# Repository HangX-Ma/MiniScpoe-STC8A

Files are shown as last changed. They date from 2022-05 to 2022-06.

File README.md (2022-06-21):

# :rocket: MiniScope on STC8A8K64D4

  

I want to use this **MiniScope** project to learn embedded system. I imitate [Open-ELL/MiniDSO-Pro](https://gitee.com/open-ell/mini-dso-pro) to make a **MiniScope** on my own but the hardware and software seems not suitable for me on account of self-changes. I have written a convenient system library for _STC8x_ easy usage. Currently I only finish the _STC8Ax_ and _STC8Hx_(mainly based on _STC8A8K64D_). **NEW DESIGN AVAILABLE PUBLISHED at 20220621.**

## Test Recorder
- [x] ADC Inquiry Method
- [x] ADC `VBAT` Module
- [x] UARTx Module
- [x] External Interrupt 0 and 1
- [x] TM0 and TM1 for keys scanning and VBAT information update
- [x] EEPROM Module
- [x] SSD1306 OLED
- [x] Setting options selection
- [x] Chart options selection
- [x] Wave scroll options selection
- [x] Run/Stop function

**NOTE: EC11 external Interrupt seems wrong. I think this may cause by hardware design or the EC11 device itself.**

## New Design

### PCB 3D Perspective
<center class="half">
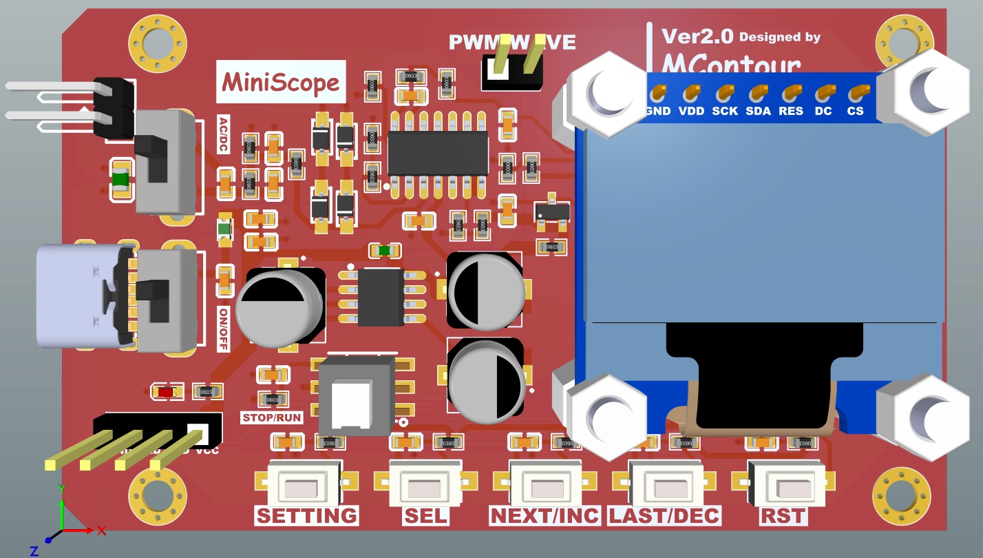
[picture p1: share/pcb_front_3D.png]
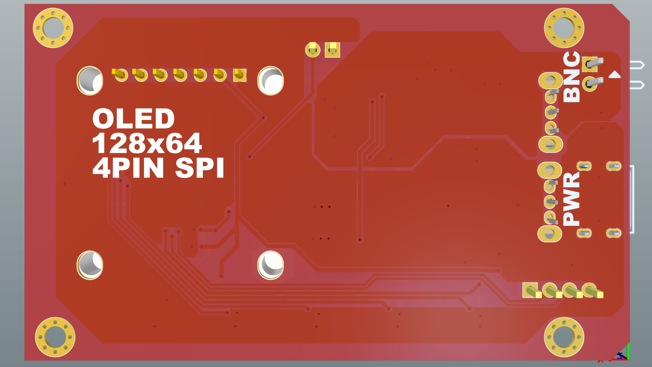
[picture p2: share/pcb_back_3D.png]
     
</center>

### PCB 2D Perspective
<center class="half">
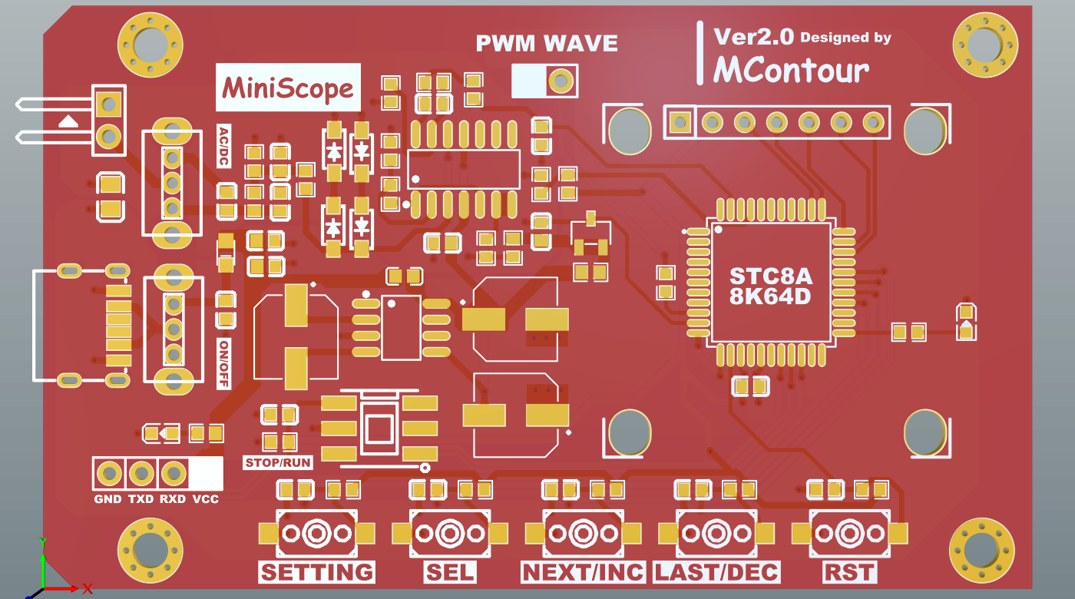
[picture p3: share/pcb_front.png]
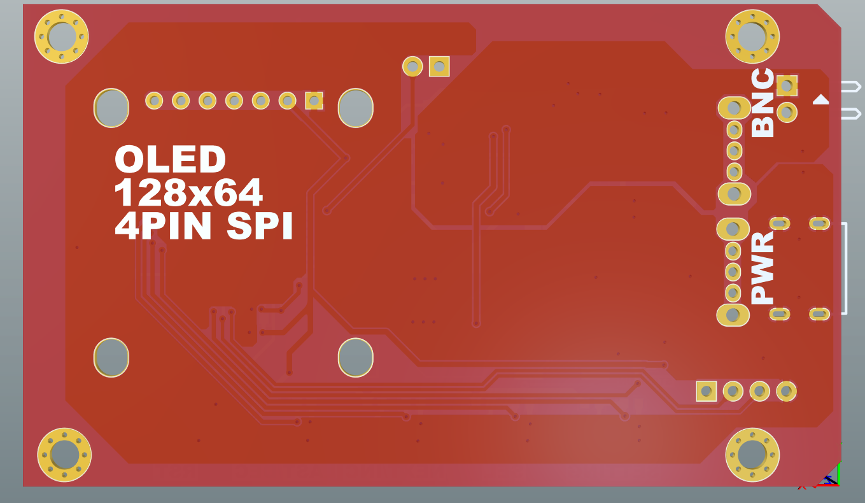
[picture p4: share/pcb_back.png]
     
</center>

### Timer Source Usage
- `TM0`: VBAT info updating rate
- `TM1`: Keys press types recognition, short or long
- `TM3`: UART1 Rx out of time

### FUNCTION INTRODUCTION

#### OPERATION INTRO:
##### Main Interface - Options Selection Mode: 
- `SW Button`:              Switch Stop/Run
- `Short Press SETTING`:    Switch to [Waveform Horizontal Scroll Mode]
- `SEL`:                    Select or deselect this option.
- `NEXT/INC`:               Jump to next option or increase value.
- `LAST/DEC`:               Jump to last option or decrease value.

##### Main Interface - Waveform Horizontal Scroll Mode:
- `SW Button`:              Switch Stop/Run
- `Short Press SETTING`:    Switch to [Options Selection Mode]
- `[SEL] SET(Horizontal waveform scroll, Valid in suspended sampling state)`:
  - `NEXT/INC`:           Jump to next option or increase value.
  - `LAST/DEC`:           Jump to last option or decrease value.
- `[SEL] RESET(Vertical waveform scroll, Valid in suspended sampling state):`
    `NEXT/INC`:           Jump to next option or increase value.
    `LAST/DEC`:           Jump to last option or decrease value.

##### Setting Interface: (SETTING)
- `Long Press SETTING`: Return to main interface or enter setting interface from main interface.
- `SEL`:                    Select or de-select this option.
- `NEXT/INC`:               Jump to next option or increase value.
- `LAST/DEC`:               Jump to last option or decrease value.

#### MAIN INTERFACE INTRO:
- `Vertical Time Range`:     "500ms", "200ms", "100ms", "50ms", "20ms", "10ms","5ms", "2ms", "1ms", "500us", "200us", "100us"(100us only used in AUTO Mode)
- `Horizontal Voltage Range`: Set voltage upper range, whose maximum value is 30V. If the voltage upper range is set to '0', system run into AUTO mode.
- `Trigger Value`:            Set trigger voltage value. The trigger position is set to the screen center.
- `Trigger Direction`:        Use up or down arrow indicator, separately representing rising edge trigger and falling edge trigger.
- `Trigger Mode`:
  - `AUTO`:   Sample continuously, whose indicator led is always turned on. SW Button is used to select RUN or STOP;
                If trigger process is successful, trigger position is set to the screen center, otherwise the waveform scrolling irregularly. FAIL will be shown.
  - `NORMAL`: Wait for prerequisite sampling. Indicator led is turned on, indicating the prerequisite sampling finished. Signal can be entered.
                After successfully triggering, display the waveform, and continue to wait for the next trigger;
                If a new trigger is successful, the new waveform will be displayed automatically. If no new trigger is successful, the screen waveform will remain and wait for the next trigger;
                (Be careful to set the correct trigger value, otherwise has been waiting for the trigger state, the screen will not display the waveform)
  - `SINGLE`: Wait for prerequisite sampling. Indicator led is turned on, indicating the prerequisite sampling finished. Signal can be entered.
                After triggering successfully, display the waveform and stop sampling, the user needs to click on the encoder to start the next sampling.
                (Be careful to set the correct trigger value, otherwise has been waiting for the trigger state, the screen will not display the waveform)

#### OPTIONS SETTING SAVING:
Long press SETTING key to leave the setting interface. If options have been changed, the program will save the setting to EEPROM.

#### LVD EVENT:
If LVD event happens, system will not allow user to operate EEPROM to save data.

#### MAIN INTERFACE STATUS: 
- `RUN`:        Sampling in progress 
- `STOP`:       Stop Sampling 
- `FAIL`:       In AUTO mode, trigger value exceeds waveform range causing trigger failure 
- `SUCC`:       In automatic mode, the trigger value displays the trigger success in the waveform range.
- `AUTO`:       Auto range.

#### SETTING INTERFACE STATUS: 
- `PMODE (drawing mode)`: 
  - Vector: waveform display using vector 
  - Dots:   waveform display using dots
- `LSB (sampling factor)`: 100 times the partial voltage factor, (8.2K+2K)/2K*100 = 510. Adjust this value subtly in accordance with actual register values.
- `BRT`:    OLED brightness

> Reference: [Open-ELL/MiniDSO-Pro](https://gitee.com/open-ell/mini-dso-pro)
> Reference: [CreativeLau/Mini-DSO](https://github.com/CreativeLau/Mini-DSO)

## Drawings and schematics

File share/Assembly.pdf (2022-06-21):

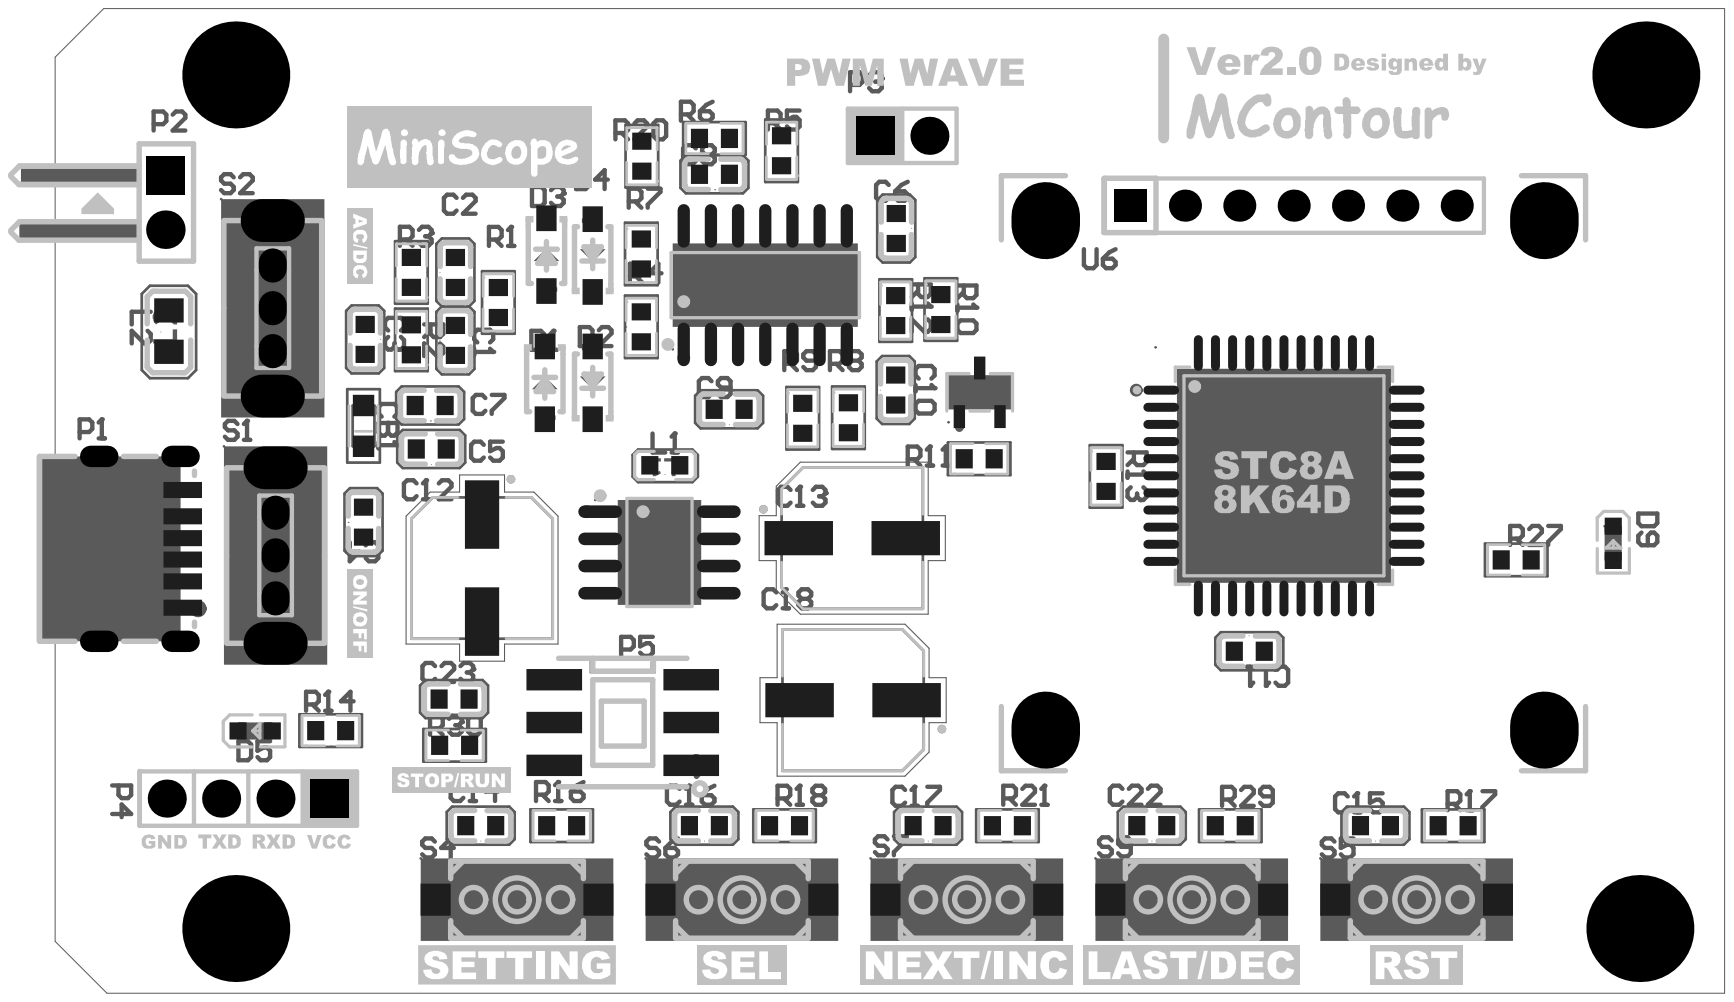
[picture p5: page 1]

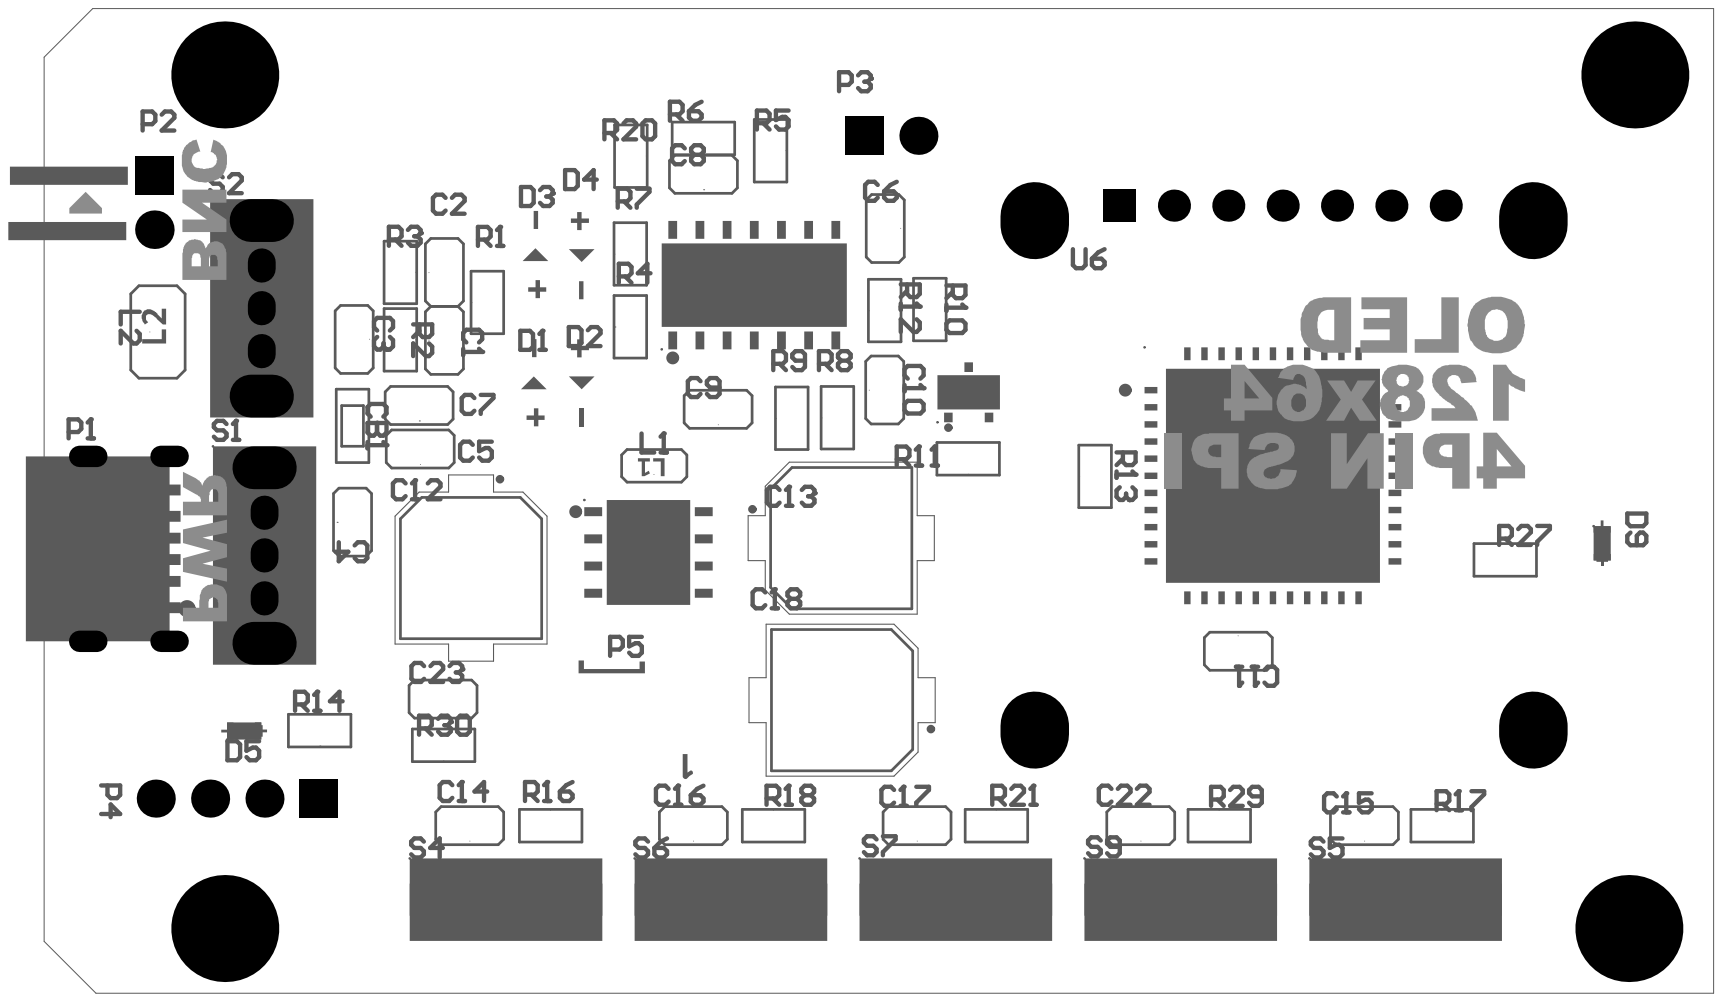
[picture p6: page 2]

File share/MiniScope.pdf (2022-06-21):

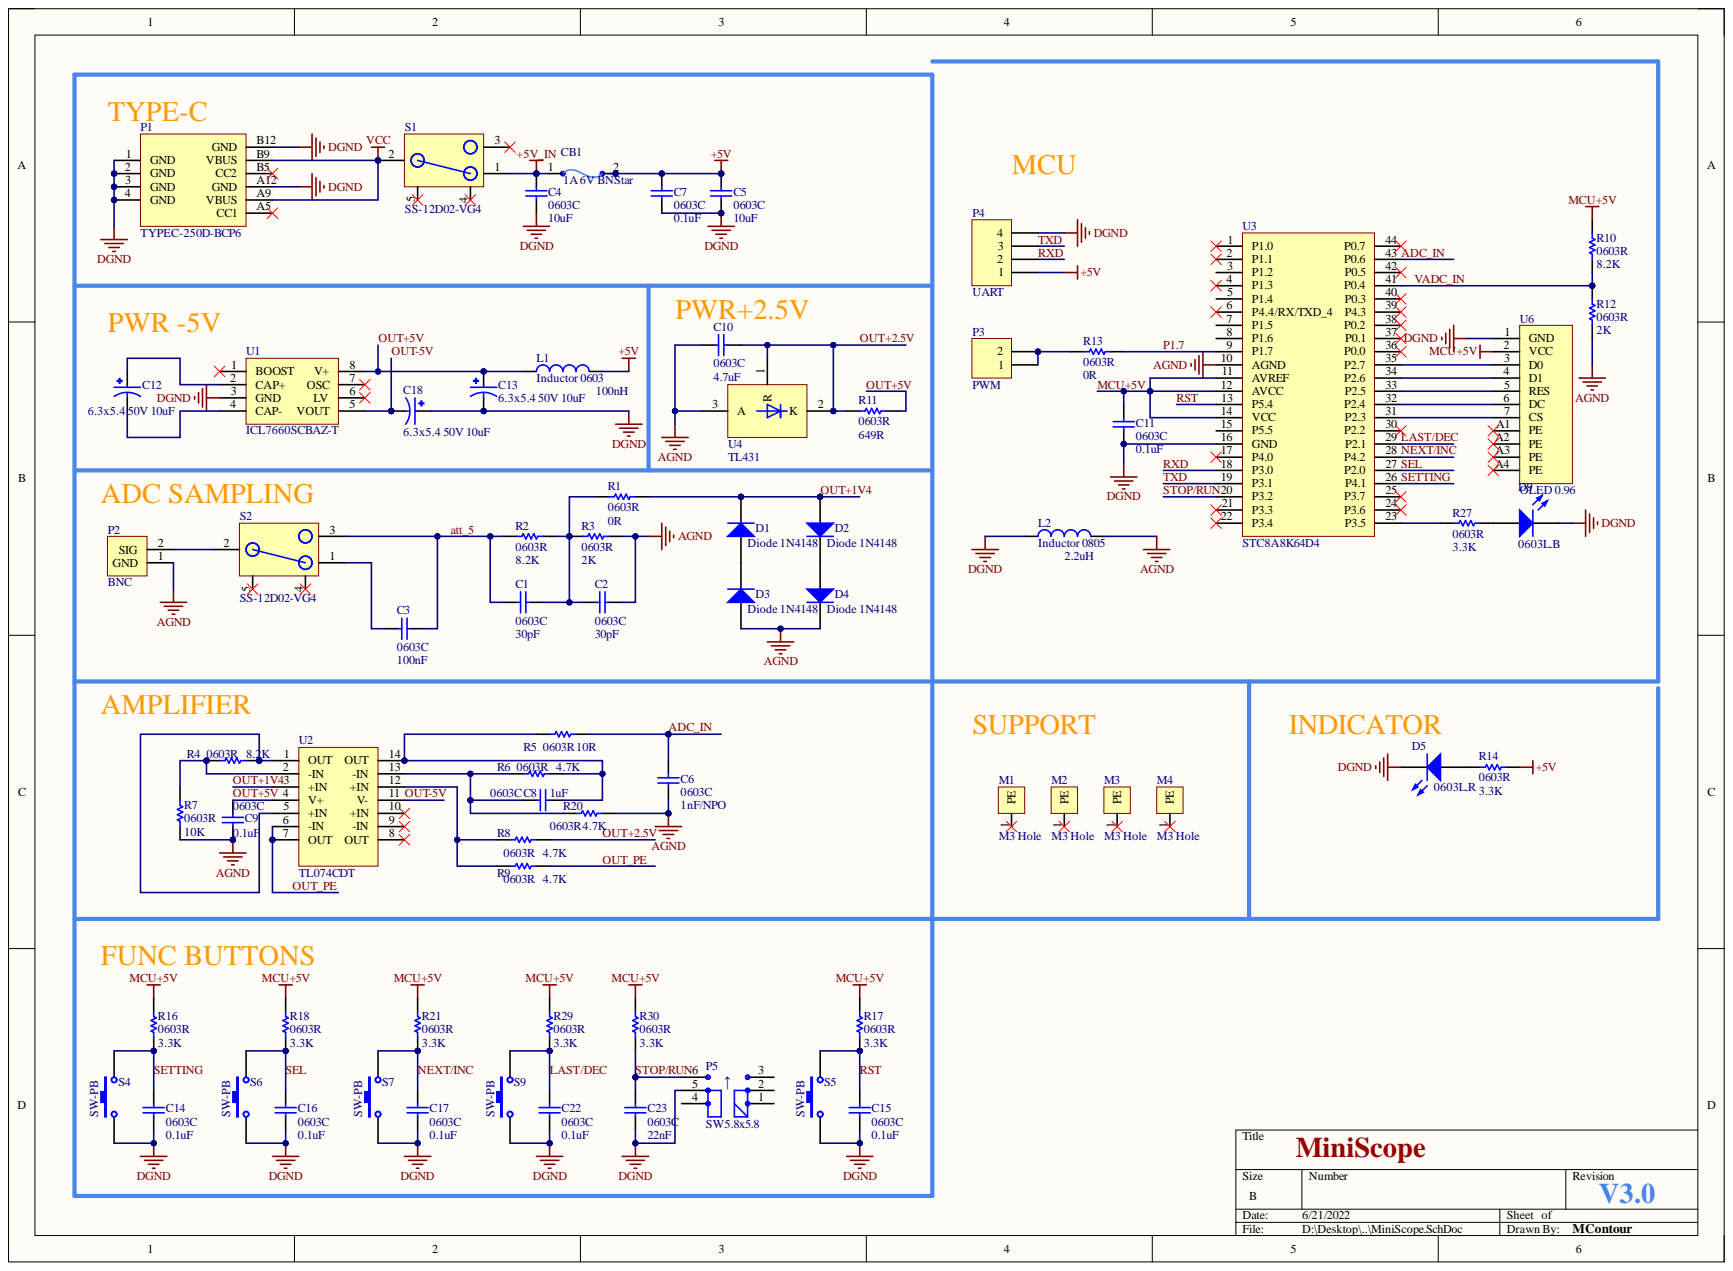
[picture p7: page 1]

AVREF 11 | | D1 4
AVCC 12 | | RES 5

C11 | VCC 14 | | CS 7

P5.5 15 | LAST/DEC | PE A1

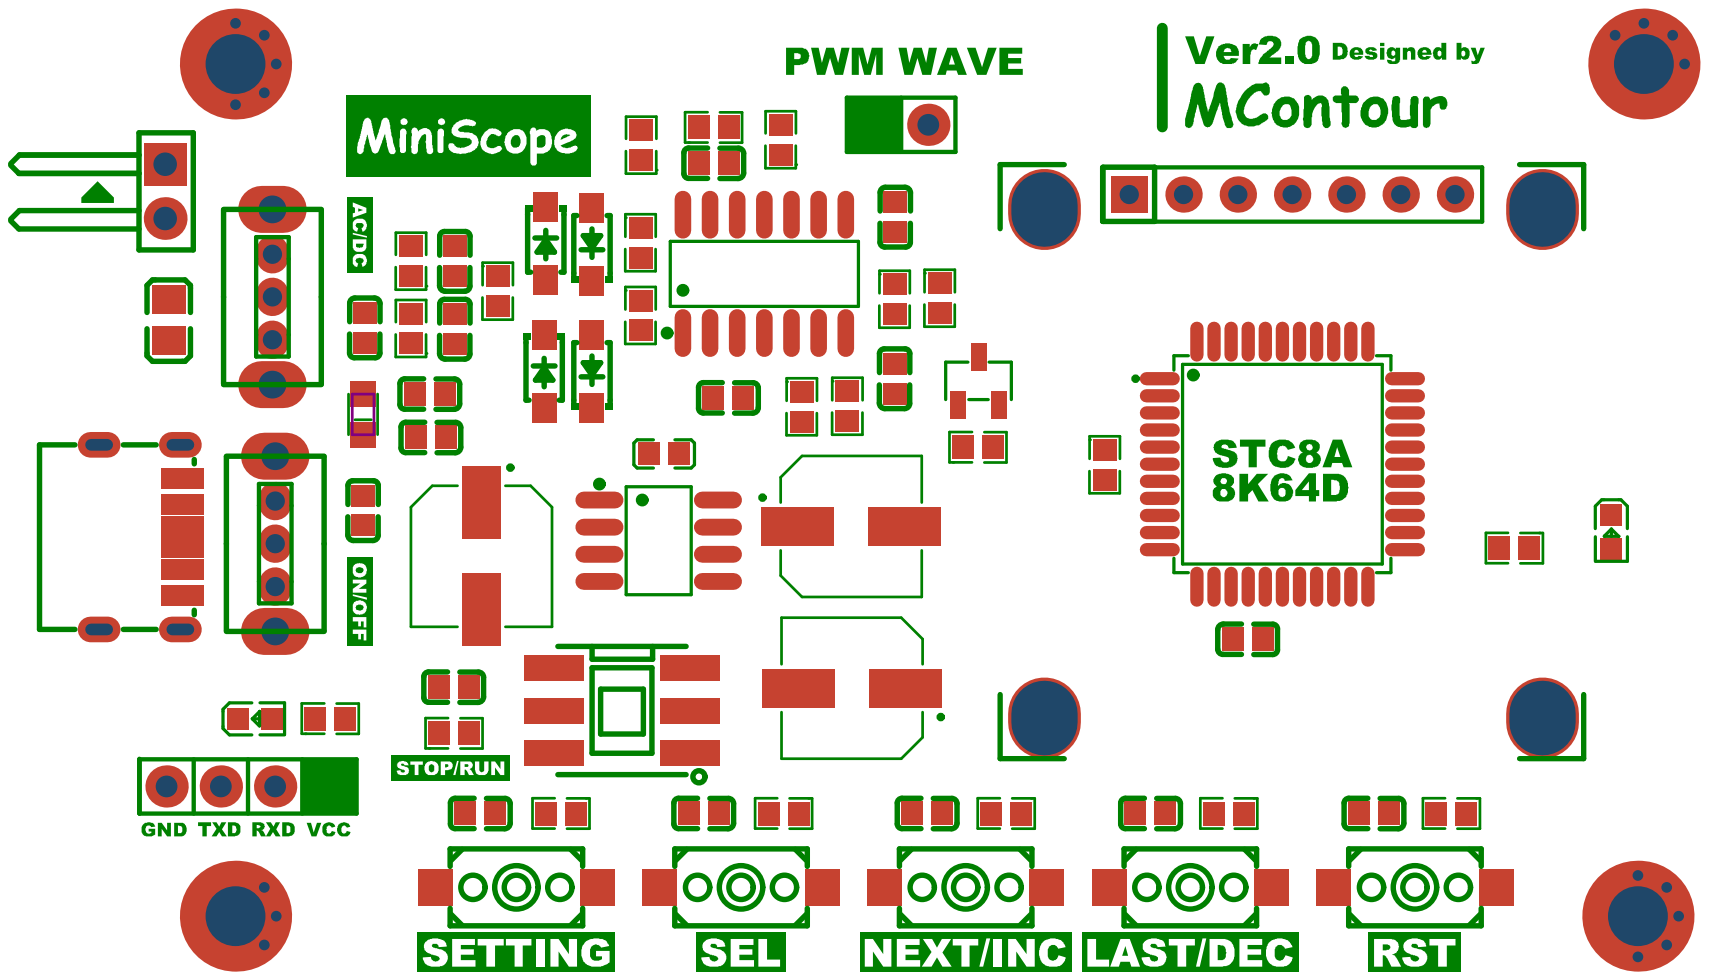
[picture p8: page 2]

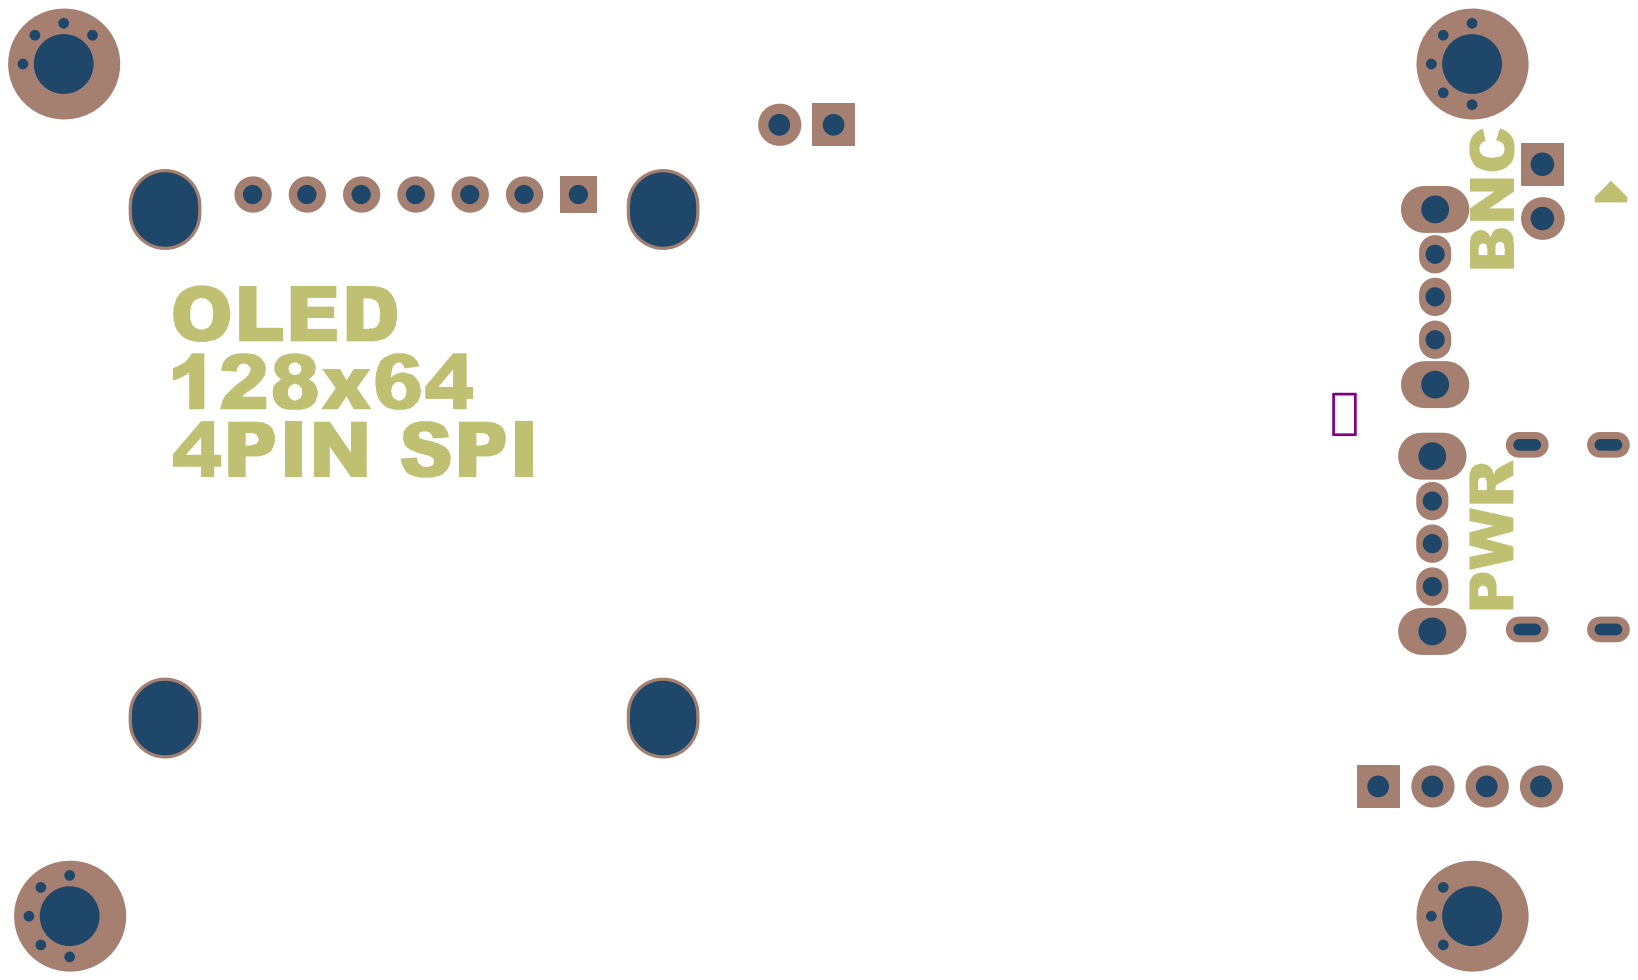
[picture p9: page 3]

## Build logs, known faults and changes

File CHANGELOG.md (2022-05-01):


## [v1.2](https://github.com/Master-sx/MiniScpoe-STC8A.git/compare/v1.1...v1.2) (2022-05-01)

### Feat

* :white_check_mark: Easy set or reset definitions

### Perf

* :white_check_mark: Core configuration for STC8A v5.0

## [v1.1](https://github.com/Master-sx/MiniScpoe-STC8A.git/compare/v1.0.4...v1.1) (2022-05-01)

### Perf

* Core configuration of STC8A v4.0
* STC8A core configuration v3.0
* Core configuration for STC8A v2.0
* Core configuration for STC8A v1.0

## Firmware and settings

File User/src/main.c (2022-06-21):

/**
 * @file main.c
 * @author MContour (m-contour@qq.com)
 * @brief main program
 * @version 0.1
 * @date 2022-05-06
 * 
 * @copyright Apache 2.0 LICENSE
 * 
 *****************************************************************************
 * Copyright (c) 2022 MContour m-contour@qq.com
 *
 * Licensed under the Apache License, Version 2.0 (the "License");
 * you may not use this file except in compliance with the License.
 * You may obtain a copy of the License at
 * 
 *     http://www.apache.org/licenses/LICENSE-2.0
 * 
 * Unless required by applicable law or agreed to in writing, software
 * distributed under the License is distributed on an "AS IS" BASIS,
 * WITHOUT WARRANTIES OR CONDITIONS OF ANY KIND, either express or implied.
 * See the License for the specific language governing permissions and
 * limitations under the License.
 *****************************************************************************
 */

/* TM0: VBAT info updating rate */
/* TM1: Keys press types recognition, short or long */
/* TM3: UART1 Rx out of time */

/*
    -----------------------------------------  [INTRODUCTION]  -----------------------------------------
    OPERATION INTRO:
        Main Interface - Options Selection Mode: 
            SW Button:              Switch Stop/Run
            Short Press SETTING:    Switch to [Waveform Horizontal Scroll Mode]
            SEL:                    Select or deselect this option.
            NEXT/INC:               Jump to next option or increase value.
            LAST/DEC:               Jump to last option or decrease value.


        Main Interface - Waveform Horizontal Scroll Mode:
            SW Button:              Switch Stop/Run
            Short Press SETTING:    Switch to [Options Selection Mode]
            [SEL] SET(Horizontal waveform scroll, Valid in suspended sampling state):
                NEXT/INC:           Jump to next option or increase value.
                LAST/DEC:           Jump to last option or decrease value.
            [SEL] RESET(Vertical waveform scroll, Valid in suspended sampling state):
                NEXT/INC:           Jump to next option or increase value.
                LAST/DEC:           Jump to last option or decrease value.

        Setting Interface: (SETTING)
            Long Press SETTING: Return to main interface or enter setting interface from main interface.
            SEL:                    Select or de-select this option.
            NEXT/INC:               Jump to next option or increase value.
            LAST/DEC:               Jump to last option or decrease value.
    ----------------------------------------------------------------------------------------------------
    MAIN INTERFACE INTRO:
        Vertical Time Range:     "500ms", "200ms", "100ms", "50ms", "20ms", "10ms","5ms", "2ms", "1ms", "500us", "200us", "100us"(100us only used in AUTO Mode)
        Horizontal Voltage Range: Set voltage upper range, whose maximum value is 30V. If the voltage upper range is set to '0', system run into AUTO mode.
        Trigger Value:            Set trigger voltage value. The trigger position is set to the screen center.
        Trigger Direction:        Use up or down arrow indicator, separately representing rising edge trigger and falling edge trigger.
        Trigger Mode:
            AUTO:   Sample continuously, whose indicator led is always turned on. SW Button is used to select RUN or STOP;
                    If trigger process is successful, trigger position is set to the screen center, otherwise the waveform scrolling irregularly. FAIL will be shown.
            NORMAL: Wait for prerequisite sampling. Indicator led is turned on, indicating the prerequisite sampling finished. Signal can be entered.
                    After successfully triggering, display the waveform, and continue to wait for the next trigger;
                    If a new trigger is successful, the new waveform will be displayed automatically. If no new trigger is successful, the screen waveform will remain and wait for the next trigger;
                    (Be careful to set the correct trigger value, otherwise has been waiting for the trigger state, the screen will not display the waveform)
            SINGLE: Wait for prerequisite sampling. Indicator led is turned on, indicating the prerequisite sampling finished. Signal can be entered.
                    After triggering successfully, display the waveform and stop sampling, the user needs to click on the encoder to start the next sampling.
                    (Be careful to set the correct trigger value, otherwise has been waiting for the trigger state, the screen will not display the waveform)
    ----------------------------------------------------------------------------------------------------
    OPTIONS SETTING SAVING:
        Long press SETTING key to leave the setting interface. If options have been changed, the program will save the setting to EEPROM.
    LVD EVENT:
        If LVD event happens, system will not allow user to operate EEPROM to save data.
    ----------------------------------------------------------------------------------------------------
    MAIN INTERFACE STATUS: 
        RUN:        Sampling in progress 
        STOP:       Stop Sampling 
        FAIL:       In AUTO mode, trigger value exceeds waveform range causing trigger failure 
        SUCC:       In automatic mode, the trigger value displays the trigger success in the waveform range.
        AUTO:       Auto range.
    ----------------------------------------------------------------------------------------------------
    SETTING INTERFACE STATUS: 
        PMODE (drawing mode) : 
            Vector: waveform display using vector 
            Dots:   waveform display using dots
        LSB (sampling factor) : 100 times the partial voltage factor, (8.2K+2K)/2K*100 = 510. Adjust this value subtly in accordance with actual register values.
        BRT:    OLED brightness
    ----------------------------------------------------------------------------------------------------
 */
#include "main.h"
#include "STDIO.H"
#include "STDLIB.H"
#include "STRING.H"
#include "stc8x_sysclk.h"


bit ifKeyPressed;
static uint8_t keyPressedTimeCount;

/**
 * @brief Rewrite 'putchar' function, remapped to UARTx output
 * 
 * @param c input character
 * @return char 
 */
char putchar (char c) {
    UARTx_Send(c);

    return c;
}


int main (void) {
    /* Set P1.7 as PWM output pin, quasi bidirectional */
    P1M1 &= ~0x80;
    P1M0 &= ~0x80;
    /* Set OLED port P2.3, P2.4, P2.5, P2.6, P2.7 as quasi bidirectional */
    P2M1 &= ~0xF8;
    P2M0 &= ~0xF8;
    /* Set ADC port P0.4, P0.6 as high-impedance */
    P0M1 |= 0x50;
    P0M0 &= ~0x50;
    /* P2.0(SEL), P2.1(LAST/DEC), P2.2(EX) as high-impedance */
    P2M1 |= 0x07;
    P2M0 &= ~0x07;
    /* Set P4.1(SETTING), P4.2(NEXT/INC) as high-impedance */
    P4M1 |= 0x06;
    P4M0 &= ~0x06;
    /* Set Button P3.2 as high-impedance */
    P3M1 &= ~0x04;
    P3M0 &= ~0x04;
    /* Set indicator port P3.5 as push-pull output */
    P3M1 &= ~0x20;
    P3M0 |= 0x20;

    P_SW2  |= P_SW2_EAXFR;
    /* Falling edge interrupt */
    P2IM0  &= ~0x07;
    P2IM1  &= ~0x07;
    P4IM0  &= ~0x06;
    P4IM1  &= ~0x06;
    /* Lowest Priority */
    PINIPL &= ~0x14;
    PINIPH &= ~0x14;
    /* Enable I/O interrupt */
    P2INTE |= 0x07;
    P4INTE |= 0x06;
    P_SW2 &= ~P_SW2_EAXFR;
    
    RST_Init();
    PWM_config();
    Switch_Init();
    TM0_Init();
    UART1_Init();
    TM1_Init();
    Read_Options();
    GlobalVar_Init();
    delay_nus(50);

    /* OLED initialization */
    OLED_Init();
    OLED_SetFontWidth(6);
    PlotChart();
    OLED_Display();

    EA = SETBIT;


    while (1) {
        /* Update voltage infor of battery */
        if (G_UpdateVBAT_FLAG) {
            VBAT = Get_BATV(ADC_CONTR_ADC_CHS_VAL12, VBAT_RATIO);
            G_UpdateVBAT_FLAG = CLRBIT;
        }

        GetWaveData(); // Sample waveform

        if (G_State_Settings_FLAG) {
            runWhenInSettings();
        } // Enter Settings Interface
        else if (G_ADC_Interrupt_FLAG) {
            runWhenADCInterrupt();
        } // ADC Sampling Interrupt
        else {
            runWhenADCComplete();
        } // ADC Sampling Complete
    }

    return 0;
}

void runWhenInSettings(void) {
    ADC_Sample_Ready_LED = CLRBIT;
    G_ClearDisplay_FLAG  = SETBIT;

    while (G_State_Settings_FLAG) {
        /* Update battery voltage information */
        if (G_UpdateVBAT_FLAG) {
            G_UpdateVBAT_FLAG = CLRBIT;
            VBAT = Get_BATV(ADC_CONTR_ADC_CHS_VAL12, VBAT_RATIO);
        }

        /* Update OLED Brightness */
        if (G_OLED_BrightnessChanged_FLAG) {
            G_OLED_BrightnessChanged_FLAG = CLRBIT;
            OLED_WR_CMD(0x81);
            OLED_WR_CMD(G_OLED_Brightness * 10);
        }

        /* Update parameters */
        if (G_DisplayUpdate_FLAG) {
            G_DisplayUpdate_FLAG = CLRBIT;
            PlotSettings();
            OLED_Display();
        }
    }

    /* Save Settings */
    EA = CLRBIT;
    if (G_State_OptionChanged_FLAG){
        G_State_OptionChanged_FLAG  = CLRBIT;
        G_ClearDisplay_FLAG         = CLRBIT;
        /* Save settings and display saving status*/
        PlotSaveStatus(Save_Options());
        OLED_Display();
        delay_nms(1000);
    }

    /* Refresh screen after exiting settings */
    G_ClearDisplay_FLAG = SETBIT;
    PlotChart();
    OLED_Display();
    EA = SETBIT;
}


/*
    ADCRuning=1
    |   WaveUpdate=1
    |   |   ClearWave=1
    |   |   ClearWave=0
    |   WaveUpdate=0
    ADCRuning=0
        DisplayUpdate=1
            WaveUpdate=1
            |   ClearWave=1
            |   ClearWave=0
            WaveUpdate=0
*/
void runWhenADCInterrupt(void) {
    G_ADC_Interrupt_FLAG = CLRBIT;
    ADC_Sample_Ready_LED = CLRBIT;

    if (G_ADC_Running_FLAG) {
        P_SW2  |= P_SW2_EAXFR;
        /* Disable I/O interrupt P4.2, P2.1 */
        P2INTE &= ~0x02;
        P4INTE &= ~0x04;
        P_SW2 &= ~P_SW2_EAXFR;

        if (G_WaveUpdate_FLAG) {
            G_WaveUpdate_FLAG   = CLRBIT;
            G_ClearDisplay_FLAG = SETBIT;

            if (G_ClearWave_FLAG) {
                G_ClearWave_FLAG = CLRBIT;
                memset(ADCbuf, 0x00, ADC_SAMPLE_BUF_SIZE * 2);
                G_WaveFreq          = 0;
                G_TriggerFail_FLAG  = CLRBIT;
                G_VMax              = 0;
                G_VMin              = 0;
                PlotChart();
            } // Clear waveform in buffer
            else {
                AnalyzeData();
                PlotChart();
                PlotWave();
            } // Display waveform in buffer
        }
        else {
            G_ClearDisplay_FLAG = CLRBIT;
            PlotChart();
        }
        OLED_Display();

        /* Not to enable external interrupt 0(Encoder Rotation) when both of ADCRunning and WaveScroll set. */
        if (!G_WaveScroll_FLAG) {
            TCON_IE0    = CLRBIT;
            P_SW2  |= P_SW2_EAXFR;
            /* Enable I/O interrupt P4.2, P2.1 */
            P2INTE |= 0x02;
            P4INTE |= 0x04;
            P_SW2 &= ~P_SW2_EAXFR;
        }
    } // ADC Sampling Running
    else {
        while (!G_ADC_Running_FLAG && !G_State_Settings_FLAG) {
            if (G_DisplayUpdate_FLAG) {
                 P_SW2  |= P_SW2_EAXFR;
                /* Disable I/O interrupt P4.2, P2.1 */
                P2INTE &= ~0x02;
                P4INTE &= ~0x04;

                G_DisplayUpdate_FLAG = CLRBIT;
                if (G_WaveUpdate_FLAG) {
                    G_WaveUpdate_FLAG = CLRBIT;
                    /* Analyze completed sampling data in buffer */
                    AnalyzeData();
                    G_ClearDisplay_FLAG = SETBIT;

                    /* Clear display and draw waveform */
                    if (G_ScaleH == G_ScaleH_tmp) {
                        /* Since the sampling points limitation, scaling waveform along horizontal is not support.
                           Show waveform only when time scale is same as that when sampling completed */
                        PlotChart();
                        PlotWave();
                    }
                    else {
                        G_WaveFreq = 0; //Clear G_WaveFreq，display '****Hz'
                        PlotChart();
                    }
                } // Clear display and draw no waveform
                else
                {
                    G_ClearDisplay_FLAG = CLRBIT;
                    PlotChart();
                } // Update parameters on display only and maintain waveform

                OLED_Display();
                TCON_IE0    = CLRBIT;

                /* Enable I/O interrupt P4.2, P2.1 */
                P2INTE |= 0x02;
                P4INTE |= 0x04;
                P_SW2 &= ~P_SW2_EAXFR;
            }
        } // ADC Sampling Stopped 
    }
}


void runWhenADCComplete() {
    if (G_TriggerMode == TriggerSel_Single)
    {
        P_SW2  |= P_SW2_EAXFR;
        /* Disable I/O interrupt P4.2, P2.1 */
        P2INTE &= ~0x02;
        P4INTE &= ~0x04;
        G_ADC_Interrupt_FLAG    = SETBIT;
        G_DisplayUpdate_FLAG    = CLRBIT;
        G_WaveUpdate_FLAG       = CLRBIT;
        G_ADC_Running_FLAG      = CLRBIT; // ADC Stop running 
        AnalyzeData();
        G_ClearDisplay_FLAG     = SETBIT;
        PlotChart();
        PlotWave();
        OLED_Display();
        TCON_IE0                = CLRBIT;
        /* Enable I/O interrupt P4.2, P2.1 */
        P2INTE |= 0x02;
        P4INTE |= 0x04;
        P_SW2 &= ~P_SW2_EAXFR;
    } // ADC Sampling Complete - Single Trigger Mode
    else {
        G_ClearDisplay_FLAG     = SETBIT;   // Reset screen clearance flag
        AnalyzeData();                      // Analyze sampled data
        PlotChart();                        // Draw main interface
        PlotWave();                         // Draw waveform
        OLED_Display();
    } // ADC Sampling Complete - Auto or Normal Trigger Mode
}



void GlobalVar_Init(void) {
    G_State_Settings_FLAG         = CLRBIT;                 // Not enter setting interface
    G_WaveScroll_FLAG             = CLRBIT;                 // Not enable waveform scroll
    
    G_UpdateVBAT_FLAG             = CLRBIT;                 // Reset battery update flag
    G_OLED_BrightnessChanged_FLAG = CLRBIT;                 // Reset OLED brightness update flag
    G_State_OptionChanged_FLAG    = CLRBIT;                 // Reset option changed flag

    /* Default ADC functions state */
    G_ADC_Running_FLAG            = SETBIT;                 // Set ADC running flag
    G_ADC_Interrupt_FLAG          = CLRBIT;                   // Reset ADC interrupt flag
    G_ADC_Complete_FLAG           = CLRBIT;                   // Reset ADC conversion complete flag

    /* Default Option for [setting interface] and [main interface]*/
    G_OptionInSettings            = SettingSel_PlotMode;    // default: PlotMode
    G_OptionInChart               = ChartSel_ScaleH;        // default: ScaleH
    G_MeasureWaySel               = MeasureWay_AC;          // default: AC measure way
    G_PlotModeSel                 = PlotMode_Vector;        // default: Vector

    /* Display setting */
    G_ClearDisplay_FLAG           = SETBIT;                 // Set clearing display flag
    G_ClearWave_FLAG              = CLRBIT;                 // Reset waveform erasing flag
    G_WaveUpdate_FLAG             = CLRBIT;                 // Reset waveform update flag

    /* Indicator */
    ADC_Sample_Ready_LED          = CLRBIT;                 // ADC sampling indicator off
    ifKeyPressed                  = CLRBIT;                 // Initially, keys are not pressed

    /* Basic Config */
    G_VMax_Modified             = 0;
    G_VMin_Modified             = 0;
    G_Voltage_Modified          = 0;
    G_VolV_Max_Modified         = 0;

    G_Bias_Voltage              = 8900;                     // Bias voltage weight

    /* Waveform Config */
    G_VMax                      = 0;                        // Clear maximum waveform voltage
    G_VMin                      = 0;                        // Clear minimum waveform voltage
    G_WaveAvgLengthSumNum       = 0;                        // Clear average waveform length sum counts
    G_WaveAvgLengthSum          = 0;                        // Clear average waveform length sum
    G_WaveFreq                  = 0;                        // Clear waveform frequency

    /* Trigger Config */
    G_TriggerPos                = 50;                       // Set initial trigger position
    G_TriggerPosOffset          = 0;                        // Set initial trigger offset
    G_TriggerFail_FLAG          = CLRBIT;                   // Reset trigger failure flag
    G_TriggerLevel_mV_Modified  = 2000;

    /* Disable external key interrupt [NEXT/INC] and [LAST/DEC] in waveform scroll mode when sampling */
    if (G_ADC_Running_FLAG && G_WaveScroll_FLAG) {
        P_SW2  |= P_SW2_EAXFR;
        /* Disable I/O interrupt P4.2, P2.1 */
        P2INTE &= ~0x02;
        P4INTE &= ~0x04;
        P_SW2 &= ~P_SW2_EAXFR;
    } 

    G_LVD_EVENT_FLAG            = CLRBIT;

    BGV_RAM                     = Get_RAM_REFV();
}

void RST_Init(void) {
    RSTCFG  = RSTCFG_P54RST | RSTCFG_LVDS_3V0; // Select P5.4 as the RST pin. LVD threshold voltage is 3.0V.
    RSTCFG &= ~RSTCFG_ENLVR; // Disable LVD reset
    PCON   &= ~PCON_LVDF;    // Clear interrupt flag
    delay_nus(500);
    ELVD    = SETBIT;        // Enable LVD interrupt
}


void Switch_Init(void) {
    TCON_IT0 = CLRBIT;   // Enable INT0, rising edge and falling edge interrupt

    /* External interrupt 0 level 1 priority, which can interrupt the key pressing, 
    used to identified a state that switch button is pressed or not. */
    PX0      = SETBIT; 
    EX0      = SETBIT; // Start external interrupt 0
}

void TM0_Init(void) {
    /* Timer 0, for updating voltage of battery */
    AUXR     &= ~AUXR_T0x12; // Timer clock is 12T mode
    TMOD     &= ~(TMOD_T0_CT | TMOD_T0_SEL | TMOD_T0_GATE); // Set timer work mode
    TL0      = 0xB0;         // Initial timer value LOW BYTE
    TH0      = 0x3C;         // Initial timer value HIGH BYTE
    TCON_TF0 = CLRBIT;       // Clear TF0 interrupt flag
    ET0      = SETBIT;       // Enable TM0 interrupt
    TCON_TR0 = CLRBIT;       // Timer0 stop running
} // 25ms@24.000MHz


void TM1_Init(void) {
    AUXR    &= ~AUXR_T1x12;  //Timer clock is 12T mode
    TMOD    &= ~(TMOD_T1_CT | TMOD_T1_SEL | TMOD_T1_GATE);  //Set timer work mode
    TL1      = 0xE0;         // Initial timer value LOW BYTE
    TH1      = 0xB1;         // Initial timer value HIGH BYTE
    TCON_TF1 = CLRBIT;       // Clear TF1 flag
    ET1      = SETBIT;       // Enable TM1 interrupt
    TCON_TR1 = CLRBIT;       // Timer1 stop running
} //10ms@24.000MHz

/**
 * @brief TM0 interrupt for updating battery voltage infomation on screen.
 */
void TM0_ISR_Handler(void) interrupt(TM0_VECTOR) {
    static uint8_t n;

    if (++n >= VBAT_UPDATE_FREQ) {
        n = 0;
        G_UpdateVBAT_FLAG    = SETBIT; // Update VBAT info
        G_DisplayUpdate_FLAG = SETBIT; // Refresh VBAT info display
    }
}

void TM1_ISR_Handler(void) interrupt(TM1_VECTOR) {
    if (keyPressedTimeCount >= 0 && keyPressedTimeCount < 255) {
        keyPressedTimeCount++;
    } 
    else {
        keyPressedTimeCount = 255;
    } // Prevent data overflow
    TCON_TF1 = CLRBIT; // Clear TF1 interrupt flag
}

/**
 * @brief INT0 interrupt used to determine the state of the switch button.
 */
void INT0_ISR_Handler(void) interrupt(EXTI0_VECTOR) {
    delay_nms(10); // Jitters elimination

    EX0      = CLRBIT;

    /* Main Interface: Switch Stop/Run state */
    if (!G_State_Settings_FLAG) {
        /* Disable [NEXT/INC] and [LAST/DEC]*/
        P_SW2  |= P_SW2_EAXFR;
        /* Disable I/O interrupt P4.2[NEXT/INC], P2.1[LAST/DEC] */
        P2INTE &= ~0x02;
        P4INTE &= ~0x04;
        P_SW2 &= ~P_SW2_EAXFR;

        if (SW_Button) {
            G_ADC_Running_FLAG = SETBIT;
        } 
        else {
            G_ADC_Running_FLAG = CLRBIT;
        } // Button state detection

        if (G_ADC_Running_FLAG) {
            G_WaveUpdate_FLAG    = SETBIT;
            G_ClearWave_FLAG     = SETBIT;
        }
        else {
            G_DisplayUpdate_FLAG = SETBIT;
            G_WaveUpdate_FLAG    = SETBIT;
        }
        G_ADC_Interrupt_FLAG     = SETBIT;
    }
    EX0      = SETBIT;
    TCON_IE0 = CLRBIT;
}
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

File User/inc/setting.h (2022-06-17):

/**
 * @file setting.h
 * @author MContour (m-contour@qq.com)
 * @brief Waveform setting options basic function definitions
 * @version 0.1
 * @date 2022-05-17
 * 
 * @copyright Apache 2.0 LICENSE
 * 
 *****************************************************************************
 * Copyright (c) 2022 MContour m-contour@qq.com
 *
 * Licensed under the Apache License, Version 2.0 (the "License");
 * you may not use this file except in compliance with the License.
 * You may obtain a copy of the License at
 * 
 *     http://www.apache.org/licenses/LICENSE-2.0
 * 
 * Unless required by applicable law or agreed to in writing, software
 * distributed under the License is distributed on an "AS IS" BASIS,
 * WITHOUT WARRANTIES OR CONDITIONS OF ANY KIND, either express or implied.
 * See the License for the specific language governing permissions and
 * limitations under the License.
 *****************************************************************************
 */

#ifndef __SETTING__H__
#define __SETTING__H__

//* ------------      head files      ------------
#include "core_stc8x.h"

#if (LIB_MCU_MODULE == STC8Ax)
    #include "config_stc8ax.h"
#elif (LIB_MCU_MODULE == STC8Hx)
    #include "config_stc8hx.h"
#endif


//* ------------   GLOBAL variables   ------------

//* ------------ developer definitions ------------
/* voltage division ratio = [for instance] (2K+8K)/(2K)*100 = 500 
   Algorithm limitation: STC8A8K maximum integer is 2^32, 
   SVin_ratio maximum value is (2^32/2^12/1344 = 780)
   [12 bits ADC:2^12][BGV_RAM:1344mV]  */
#define SVin_ratio_MAX          750
#define SVin_ratio_MIN          10

#define CHX_Vin_ratio_MAX       750
#define CHX_Vin_ratio_MIN       10

#define OLED_BRIGHTNESS_MAX     25      //!< Maximum OLED brightness degree
#define OLED_BRIGHTNESS_MIN     1       //!< Minimum OLED brightness degree

#define MAX_VOLTAGE_V           30000   //!< Vertical axis maximum voltage (mV)
#define MIN_VOLTAGE_V           -11000  //!< Vertical axis minimum voltage (mV)
//* ------------     functions     ------------

/**
 * @brief interval validation checker
 * @details MCU speed limitation result in the Single Sweep 
 * and Normal Sweep calculations could not complete in 100us time interval.
 */
void CheckMinTimeInterval(void);

/**
 * @brief Change interval for wave time scale (Horizontal Grid)
 * @details Time scale: 500ms, 200ms, 100ms, 50ms, 20ms, 10ms, 5ms, 2ms, 1ms, 500us, 200us, 100us 
 * @param ifNext Next scale or last scale
 */
void Change_ScaleH(bit ifNext);

/**
 * @brief Change wave sampling port voltage division ratio
 * @details ratio value has maximum and minimum limitation
 * @param ifNext Next or last ratio value
 */
void Change_SVin_ratio(bit ifNext);

/**
 * @brief Change trigger value
 * 
 * @param ifNext Increase or decrease
 */
void Change_TriggerVal(bit ifNext);

/**
 * @brief Select suitable trigger mode (loop)
 * @details 2: Single(stop sampling after triggering, manually waiting for next triggering), 
 * 1: Normal(stop sampling after triggering, automatically waiting for next triggering), 
 * 0: Auto(continuously sample, manually stop)
 * @param ifNext Next or last trigger mode
 */
void Change_TriggerMode(bit ifNext);

/**
 * @brief Change trigger position offset
 * 
 * @param ifNext Increate or decrease position offset
 */
void Change_TriggerPosOffset(bit ifNext);

/**
 * @brief Change chart options
 * @details 0:ScaleH, 1:ScaleV, 2:TriggerLevel, 3:TriggerSlope, 4:TriggerMode 5 MeasureWay
 * @param ifNext Next or last option
 */
void Change_OptionInChart(bit ifNext);

/**
 * @brief Change setting options
 * @details 0:PlotMode, 1:SVin_ratio, 2:OLED_Brightness
 * @param ifNext Next or last option
 */
void Change_OptionInSetting(bit ifNext);

/**
 * @brief Change OLED brightness
 * @details 1~254 but divided artificially to ten degrees,
 * numerically increasing or decreasing 10 per step.
 * @param ifNext Next or last brightness value
 */
void Change_OLED_Brightness(bit ifNext);

/**
 * @brief Change Plot Mode
 * @details 0: vector, 1: dot
 */
void Change_PlotMode(void);

void Change_VoltageV_Max(bit ifNext);

void Change_VoltageV(bit ifNext);

void SelectInSettings(bit ifNext);

void SelectInChart(bit ifNext);

/**
 * @brief Read options from EEPROM
 */
void Read_Options(void);

/**
 * @brief Check options read from EEPROM
 */
void Check_Options(void);


/**
 * @brief Save options to EEPROM and return the saving result
 * @return ErrorStatus, indicate whether saving process success
 */
ErrorStatus Save_Options(void);


#endif  //!__SETTING__H__

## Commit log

2022-04-26 learning C51 stage; intermediate stage
2022-05-01 feat: :white_check_mark: Easy set or reset definitions
    Add definitions in core_stc8x.h and base_stc8x.h for easy functions or registers programing. Add enum types for easy state switch.
2022-05-11 feat: Add ADC, Delay funcs; Improve other codes.
    Improve EEPROM funcs; Amend some definitions in confg_xxx.h; Add ADC and Delay funcs
2022-05-15 perf: Fix errors and add OLED basic functions
    Fixed errors in DeviceSupport and CoreSupport folders; Add ssd1306 basic usage functions.
    [main.c]
2022-05-17 feat: :rocket: Add C51 Vscode c_cpp_intelliSense; Fix bugs
    Add c51 intellisense; fix config errors; add ssd1306
    [adc.c, adc.h, chart.c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]
2022-05-21 fix: Complete UARTx function and fix bugs
    ditto
    [adc.c, adc.h, chart.c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]
2022-05-23 feat: Add UART1 DMA and FIFO, ISR.asm interrupt remapping file and others
    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
2022-05-25 perf: :zap: update UART structure
    Add FIFO for UART Tx and Rx process, tested currently
2022-05-26 fix: fix UARTx Tx
    UARTx Tx can not use the FIFO buffer due to the limitation of STC8Ax.
    Modified it to calling a interrupt before sending a byte.
    [main.c, uart.c]
2022-06-01 fix some bugs but the programs can not run well
    [adc.c, adc.h, chart.c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]
2022-06-03 EC11 seem to be damaged
    [adc.c, adc.h, global_var.h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]
2022-06-04 fix: Fix EEPROM and OLED display; Reoganize some codes to overcome the lack of encoder problem
    ditto. Add a flowchart to describe the working process. Next to realize the Wave Sampling Function.
    [global_var.h, main.c, main_ref.c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]
2022-06-04 update Flowchart svg file
2022-06-17 perf: :zap: Update display; Fix bugs in STC8Hx config file; Switch chip
    Update setting interface indicator; Fix bugs in STC8Hx config file; Fix eeprom problem; Update structure.
    [adc.c, adc.h, chart.c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]
2022-06-20 perf: :art: Fix delay_nus() func; Realize fundamental functions of the MiniScope; Further enhancement is needed.
    ditto.
    [adc.c, adc.h, chart.c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]
2022-06-20 perf: Code improvement and new features
    Delete redundant variables in global_var and add LVD detection to prohibit EEPROM at low voltage situation.
2022-06-21 docs: :rocket: New Release
    Add introduction in README.md and add project files in share dir.
    [MiniScope.SchDoc]
